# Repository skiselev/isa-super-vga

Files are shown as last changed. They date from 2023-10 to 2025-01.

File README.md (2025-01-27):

# isa-super-vga
Trident TVGA9000i based Super VGA board

## Introduction

The ISA Super VGA card is based on the Trident TVGA9000i Super VGA controller IC. It offers excellent compatibility with the original IBM VGA, as well as a good emulation of older CGA, EGA, Hercules and MDA adapters. The ISA Super VGA card was designed to be used with the [Xi 8088 Processor Board](https://github.com/skiselev/xi_8088), but it also works in IBM PC/XT and their clones. It will work in 16-bit ISA slots of AT-compatible computers, but its performance will be inferior to 16-bit VGA cards.

Note: PCB Version 1.0 requires a rework for compatibility with the original IBM PC and IBM XT computers, please see the Errata section below. This errata was fixed in the PCB Version 1.1

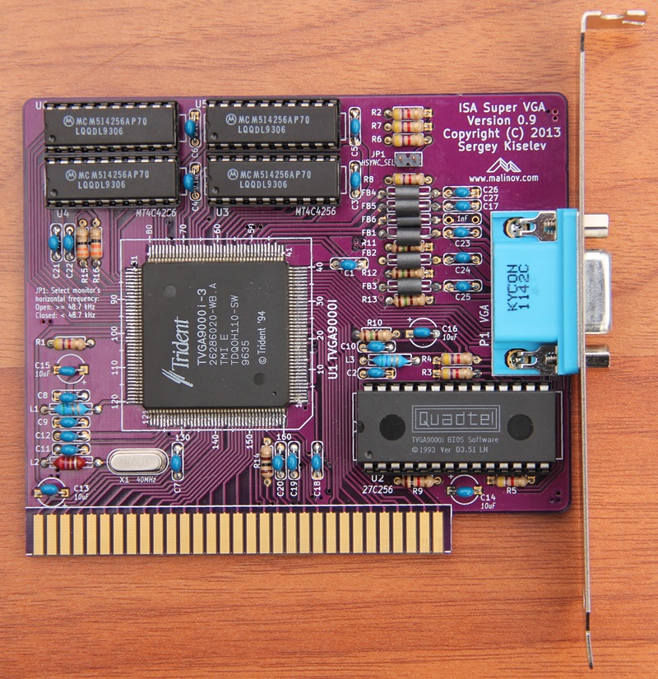
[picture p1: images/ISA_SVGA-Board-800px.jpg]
ISA SVGA V0.9 Assembled Board


## Specifications

* Supports 256 KiB or 512 KiB video memory using two or four 256 Kbit x 4 DRAM ICs.
* 8088-friendly VGA BIOS.
* Only 6 ICs (SVGA IC, BIOS, four DRAM chips), some capacitors, resistors and inductors.

## Hardware Documentation

### Schematic and PCB Layout

[Schematic - Version 1.1](KiCad/ISA_SVGA-Schematic-1.1.pdf)

[PCB Layout - Version 1.1](KiCad/ISA_SVGA-Board-1.1.pdf)

### Bill of Materials

Component Type     | Reference | Description                                               | Quantity | Possible sources and notes
------------------ | --------- | --------------------------------------------------------- | -------- | --------------------------
PCB                |           | ISA Super VGA PCB                                         | 1        | Refer to the [RetroBrew Computers Board Inventory page](https://retrobrewcomputers.org/doku.php?id=boardinventory) for ordering information, or order from a PCB manufacturer of your choice using provided Gerber or KiCad files. Here is [OSH Park project link](https://oshpark.com/shared_projects/M9jRwsu1).
Integrated Circuit | U1        | Trident TVGA9000i-3                                       | 1        | Utsource or other component dealers. Other TVGA9000i versions can be used (e.g. TVGA9000i-1)
Integrated Circuit | U2        | 27C256 UV erasable EPROM or OTP ROM                       | 1        | Unicorn Electronics, Jameco, Mouser (OTP ROM)
Integrated Circuit | U3 - U6   | Micron MT4C4256, Motorola MCM514256, or similar 256 Kbit x 4 DRAM, 70ns or less | 2 or 4 | Unicorn Electronics. Install 4 for the total memory of 512 KiB or two for 256 KiB.
Capacitor          | C1 - C12  | 0.1 uF ceramic, 5.08 mm pitch                             | 12       | Mouser 810-FG28X7R1H104KNT0 
Capacitor          | C13 - C16 | 10 uF, 16V, multilayer ceramic or tantalum, 5.08 mm pitch | 4        | Mouser 810-FG26X7R1E106KRT0 
Capacitor          | C17       | 1 nF ceramic, 5.08 mm pitch                               | 1        | Mouser 810-FG28C0G2A102JNT6
Capacitor          | C18       | 470 pF ceramic, 5.08 mm pitch                             | 1        | Mouser 810-FG28C0G1H471JNT0 
Capacitor          | C19       | 100 pF ceramic, 5.08 mm pitch                             | 1        | Mouser 810-FG28C0G1H101JNT0 
Capacitor          | C20 - C27 | 47 pF ceramic, 5.08 mm pitch                              | 8        | Mouser 810-FG28C0G1H470JNT0
Resistor           | R1 - R8   | 4.7 k, 1/4 W                                              | 8        | Mouser 291-4.7K-RC
Resistor           | R9        | 1 k, 1/4 W                                                | 1        | Mouser 291-1K-RC
Resistor           | R10 - R13 | 150 Ohm, 1/4 W                                            | 4        | Mouser 291-150-RC
Resistor           | R14       | 100 Ohm, 1/4 W                                            | 1        | Mouser 291-100-RC
Resistor           | R15, R16  | 33 Ohm, 1/4 W                                             | 2        | Mouser 291-33-RC
Connector          | P1        | DE15F, right angle PCB mount                              | 1        | Mouser 806-K66X-E15S-NJVESA, 571-1-1734344-1 (blue color), 806-K66X-E15S-NJ30
Connector          | JP1       | 2 pin header                                              | 1        | Mouser 649-68002-102HLF
Inductor           | L1, L3    | 5.7 uH                                                    | 2        | Mouser 542-78F5R6J-RC
Inductor           | L2        | 2.7 uH                                                    | 1        | Mouser 542-78F2R7-RC
Filter             | FB1 - FB6 | EMI Filter Bead                                           | 6        | Mouser 623-2743001112LF
Crystal            | X1        | 40 MHz                                                    | 1        | Mouser 815-ABL-40-B2
Crystal Insulator  | X1        | Bivar CI-192-028-SR                                       | 1        | Mouser 749-CI-192-028-SR, optional, to prevent crystal from shortcircuiting the traces underneath it.
IC Socket          | U2        | 28 pin 600 mil (wide) DIP socket                          | 1        | Mouser 517-4828-6000-CP
IC Socket          | U3 - U6   | 20 pin 300 mil (narrow) DIP socket                        | 4        | Mouser 517-4820-3000-CP
Bracket            |           | ISA card bracket - Keystone 9200-1                        | 1        | Mouser 534-9200-1, or a [3D printed bracket](https://www.thingiverse.com/thing:6473572)

### Construction Notes

#### Display Type Detection

* TVGA9000i VGA controller uses VGA connector pin 12 as **MONITOR** signal to detect the of type of the display. Older, pre-[DDC](https://en.wikipedia.org/wiki/Display_Data_Channel) displays made approximately until 1995, have that signal either unconnected - for color monitors, or grounded - for monochrome monitors. Newer displays use that signal as the DDC/SDA signal. Unfortunately, it can result in TVGA9000i incorrectly detecting the monitor as monochrome. If you're not planning to use monochrome monitor, you can skip FB6 and C17 components. In this case R6 will be pulling the MONITOR signal up, and TVGA9000i will detect the display as a color one.

## Changes

### Version 1.1

* Fix ALE errata. ALE signal is now connected to 5V
* Slightly move VGA DE-9F connector (about 1.27 mm up and 0.8 mm back) to better comply with ISA card size and bracket placement specifications

### Version 1.0

* Minor board modifications around JP1

## Errata

### Version 1.1
* C17 is incorrectly marked as 1 uF on the silkscreen. The correct value is 1 nF, as shown in the BoM. Also see **Display Type Detection** note above.

### Version 1.0

* The original IBM PC, the original IBM XT, and XT clones that closely follow IBM XT schematic do not implement the ALE signal properly. In these computers the ALE signal occasionally activated during DMA cycles, for example during memory refresh, while the address on the address bus is invalid. This confuses the Trident TVGA controller. The following rework is required to make ISA Super VGA work in these computers: The TVGA9000 ALE signal needs to be disconnected from the ISA ALE signal, and connected to the 5V power signal. The photo below shows such modification (photo credit: [keropi](https://forum.vcfed.org/index.php?members/keropi.23086/) at [VCFed forum](https://forum.vcfed.org/index.php)).

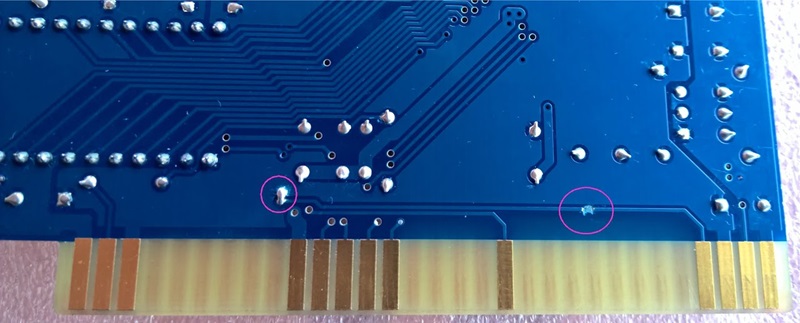
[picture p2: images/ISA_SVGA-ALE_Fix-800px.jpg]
ISA SVGA ALE Fix


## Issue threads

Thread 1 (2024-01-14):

thanks to the author & a couple of tips about building

giobbino, 2024-01-14:
First of all, thank you very much for your projects! I've built the ISA Super VGA card and now I'm waiting the PCBs and the parts for the 8088 and the FDD controller (I've already built the XT-IDE too). For us who can't design such complicated project on our own, these shared projects are very welcome!
----------------------------------------------------------------------
A couple of tips for anybody who will build the Super VGA card, based on my personal experience (I've built five units, all of them working fine):

1) if you planned to use just two RAM chips, use U3 and U4 sockets. Maybe you can use U5 and U6 instead, but I didn't try.

2) if your card doesn't work at first, and everything seems OK (solder joints, etc.), clean it with hot water, dish soap and a brush tooth (and of course dry it before to test!). I've found the Trident chip seems to be quite sensible to flux.

3) On Aliexpress you will easily find 5.6 uH inductance, that works fine instead of the 5.7 uH (I didn't find that value).

4) If you're uncertain about where to buy the VGA chip, I bought 3 units from this seller: https://www.aliexpress.com/item/1005005840301738.html  (seller: https://qimingyuan.aliexpress.com/store/1102671983).
They sent me the chips, that were clearly NOS, in a very good and resistant plastic package.

5) if you're uncertain about where to buy the RAM chips, I bought them from this seller:
https://www.aliexpress.com/item/1005005868001142.html (seller: https://www.aliexpress.com/store/3683098)
The chips worked fine.

Please note that I'm not affiliated to the sellers; it's just a suggestion based on my personal experience.

6) if you want to 3D print the bracket, get this one: https://www.tinkercad.com/things/l7DXN7Z4p88-vga-xt-8-bit-malinov-bracket

Hope it helps!

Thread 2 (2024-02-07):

3D printed bracket

giobbino, 2024-02-07:
For anybody who wish to print its own bracket, I released an STL file on Thingiverse:

https://www.thingiverse.com/thing:6473572

The same object also fits the Floppy disk and serial controller by Sergey.

hope it could help.

skiselev, 2024-02-07:
That looks great.
I've added it to the BoM.
Also added it to the [Monster FDC](https://github.com/skiselev/monster-fdc) project that uses the same bracket.
Thank you!

Closed 2024-02-07.

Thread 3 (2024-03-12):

BOM C20 -C27 capacitors, Mouser 810-FK28C0G1H470J, are obsolete and no longer available from Mouser.

wrljet, 2024-03-12:
Sergey,

The C20 - C27 47pF ceramic capacitors listed in the BOM, Mouser 810-FK28C0G1H470J, are obsolete and no longer available at Mouser.

Possible substitute:  810-FG28C0G1H470JNT0

The C18 and C19 small ceramic caps are also listed as not recommended for new designs.

Bill

skiselev, 2025-01-10:
Thanks for reporting!
Fixed here: https://github.com/skiselev/isa-super-vga/commit/ecea28522af35081063dd6427351b2361739830f
I also replaced other TDK FK series capacitors with the FG series.
Sorry, took some time to update the BoM...

Closed 2025-01-10.

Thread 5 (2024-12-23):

TVGA9000i ISA vs MCA pinout

kladogen, 2024-12-23:
Hi, I have built your design - thanks allot for it!! I have purchased 3 TVGA9000i chips but the board is not working, I have checked everything multiple times. So I just found that the TVGA9000i comes in two pinouts ISA and MCA, how can I check that the chips I have are ISA?

skiselev, 2024-12-23:
Any TVGA9000i chip can work either in ISA or MCA mode. The mode selected by this ISA SVGA board is ISA mode.
Sorry to hear your board is not working.
Do you get any signs of life at all? E.g. BIOS beeps? (If I recall correctly, there is a series of three or so short beeps if VGA memory test fails)
One common issue is soldering of the TVGA9000i chip, I'd recommend making sure that there are no solder bridges between pins. Also sometimes, pins are not thoroughly soldered. Both issues can be checked using a multimeter with thin, needle probes.

Hope this helps...

skiselev, 2025-01-10:
No response in a few weeks, closing the issue. Feel free to reopen or create another issue.

Closed 2025-01-10.

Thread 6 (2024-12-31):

EPROM speed

kladogen, 2024-12-31:
Hi, happy new year.
I would like to know what are the recommended ns for the EPROM. I have checked everything on my board - no shorts. Also I have checked the pcb connections according to schematic. I have changed RAMs no success. The only thing I have tried is faster EPROM since the ones I have are 100ns and 120ns. Could this be the problem? I'm using the tvga9000i-D4.01E.bin firmware.

kladogen, 2025-01-01:
The problem is not with the speed of the EPROM. The 100ns works fine.

Closed 2025-01-10.

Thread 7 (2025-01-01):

Crystal casing comes into contact with pads

kladogen, 2025-01-01:
The reason my board did not work was that the crystal case is conductive and came into contact with the pads under the crystal when the crystal is pushed to come in contact with the PCB (us it is supposed to). This causes a shortcircuit between the crystal pins and off course the circuit does not work. The solution is to leave to some space between the crystal and the board or to put some insulating tape under the crystal. In next version of the PCB the crystal pads could become smaller.

wrljet, 2025-01-01:
I don't have that issue with mine.  But, Digi-key, etc. sell little mylar insulators designed to go underneath standard crystal footprints.  I used to use these on my cheap PCBs years ago before I had solder mask.

kladogen, 2025-01-01:
Maybe a comment could be added to the BOM to save others from the same problem. It took me a week to find it after checking all connections on the PCB. The crystal was the last component I checked. At least it worked for 2025!

skiselev, 2025-01-10:
@wrljet do you have a part number, perhaps I can add that do the BoM?

wrljet, 2025-01-11:
Bivar (the manufacturer)  CI-192-028-SR

DigiKey  492-1039-ND
Mouser 749-CI-192-028-SR

But for what it's worth, I don't see a problem with the PCB causing a need for these insulators.
The expected crystal package won't short anything.

Bill

skiselev, 2025-01-27:
Thanks @wrljet!
I added the insulator to the BoM: https://github.com/skiselev/isa-super-vga/commit/ec1888477d16e3e7cb4c25714abd4655e719a455

Closed 2025-01-27.

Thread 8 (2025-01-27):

3D Printer Bracket problem

kladogen, 2025-01-27:
I have 3D printed the bracket (https://www.thingiverse.com/thing:6473572) but it is about 7mm longer at the top. Although the total length of the bracket is correct it seems it was designed before the VGA connector was moved, and it does not fit with current connector position.

skiselev, 2025-01-27:
I never ever moved the connector on that board.
It might be the issue with the 3D bracket design, in which case @giobbino is probably the right person to contact.
See: https://github.com/skiselev/isa-super-vga/issues/2

Closed 2025-01-27.

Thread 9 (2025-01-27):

Bracket dimensions seem to be incorrect

skiselev, 2025-01-27:
@giobbino Can you please check the bracket dimensions?
They should be the same as or very close to [Keystone Electronics
9200-1](https://www.mouser.com/datasheet/2/215/200-1-741899.pdf).
Looks like the position of the connector is not correct.
The center of the connector should be 49.83 mm from the top (50 mm is close enough). In your design it seems to be 55 mm or so.

giobbino, 2025-01-29:
I'm not sure why it's wrong for you, since it worked for me. However not a big deal, I can change the project and add a new file to the page.

Just to be sure: should I move the VGA connector hole 5 mm upward?

kladogen, 2025-01-29:
If the VGA connector is move 5mm up then the bracket corner should be at the correct height for a standard PC.

giobbino, 2025-01-29:
https://www.thingiverse.com/thing:6473572/files
added the new STL connector
cheers

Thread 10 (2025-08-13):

TIP: No need to order **Crystal Insulator** - Alternative

iosoft, 2025-08-13:
No need to buy/order **Crystal Insulator** (Bivar CI-192-028-SR / Mouser 749-CI-192-028-SR)

Just buy any cheapest 2-pin SMD type Crystal with plastic spacer.
Straighten the legs of the SMD type Crystal.
Remove and reuse the plastic spacer.
Fits perfectly.

See, I did -

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

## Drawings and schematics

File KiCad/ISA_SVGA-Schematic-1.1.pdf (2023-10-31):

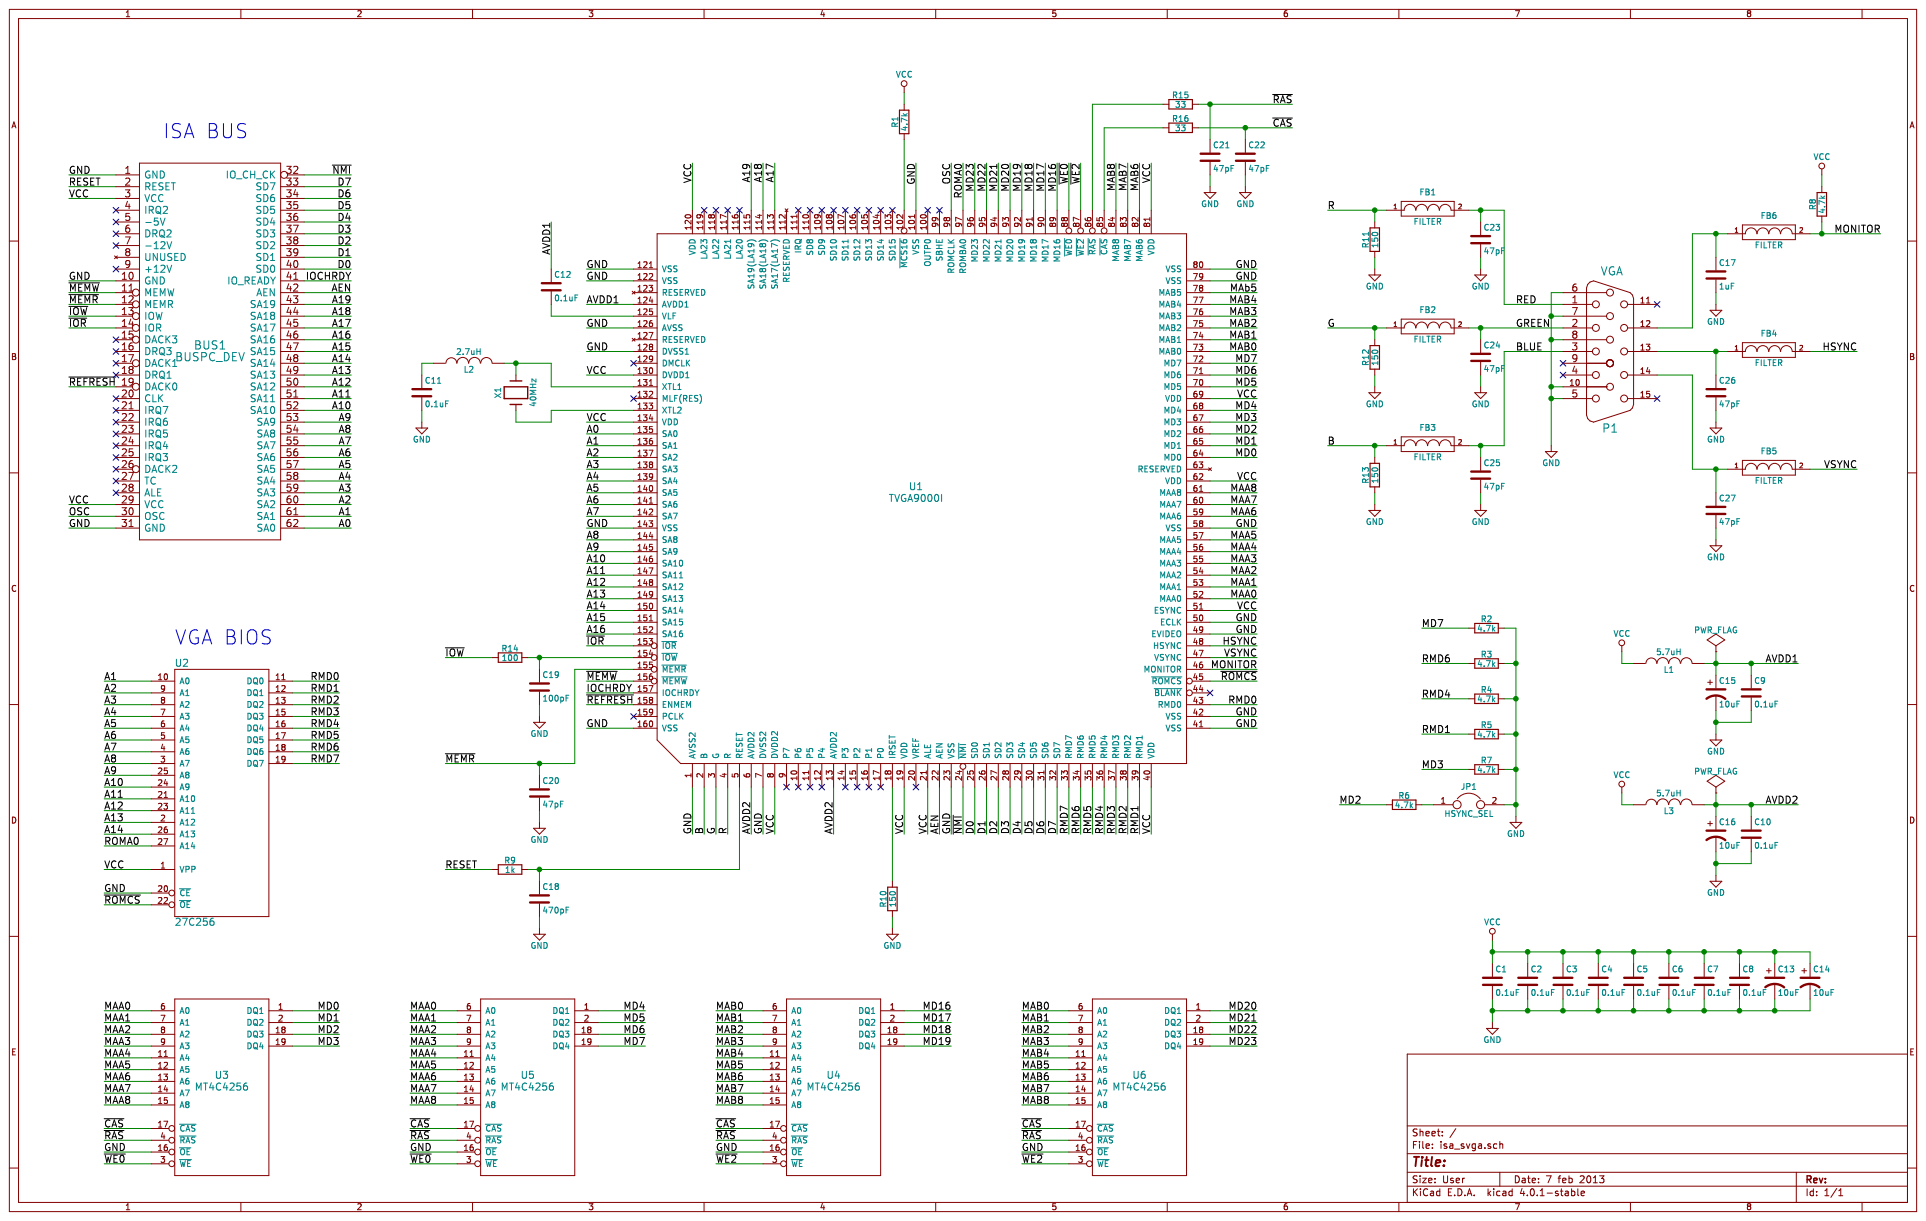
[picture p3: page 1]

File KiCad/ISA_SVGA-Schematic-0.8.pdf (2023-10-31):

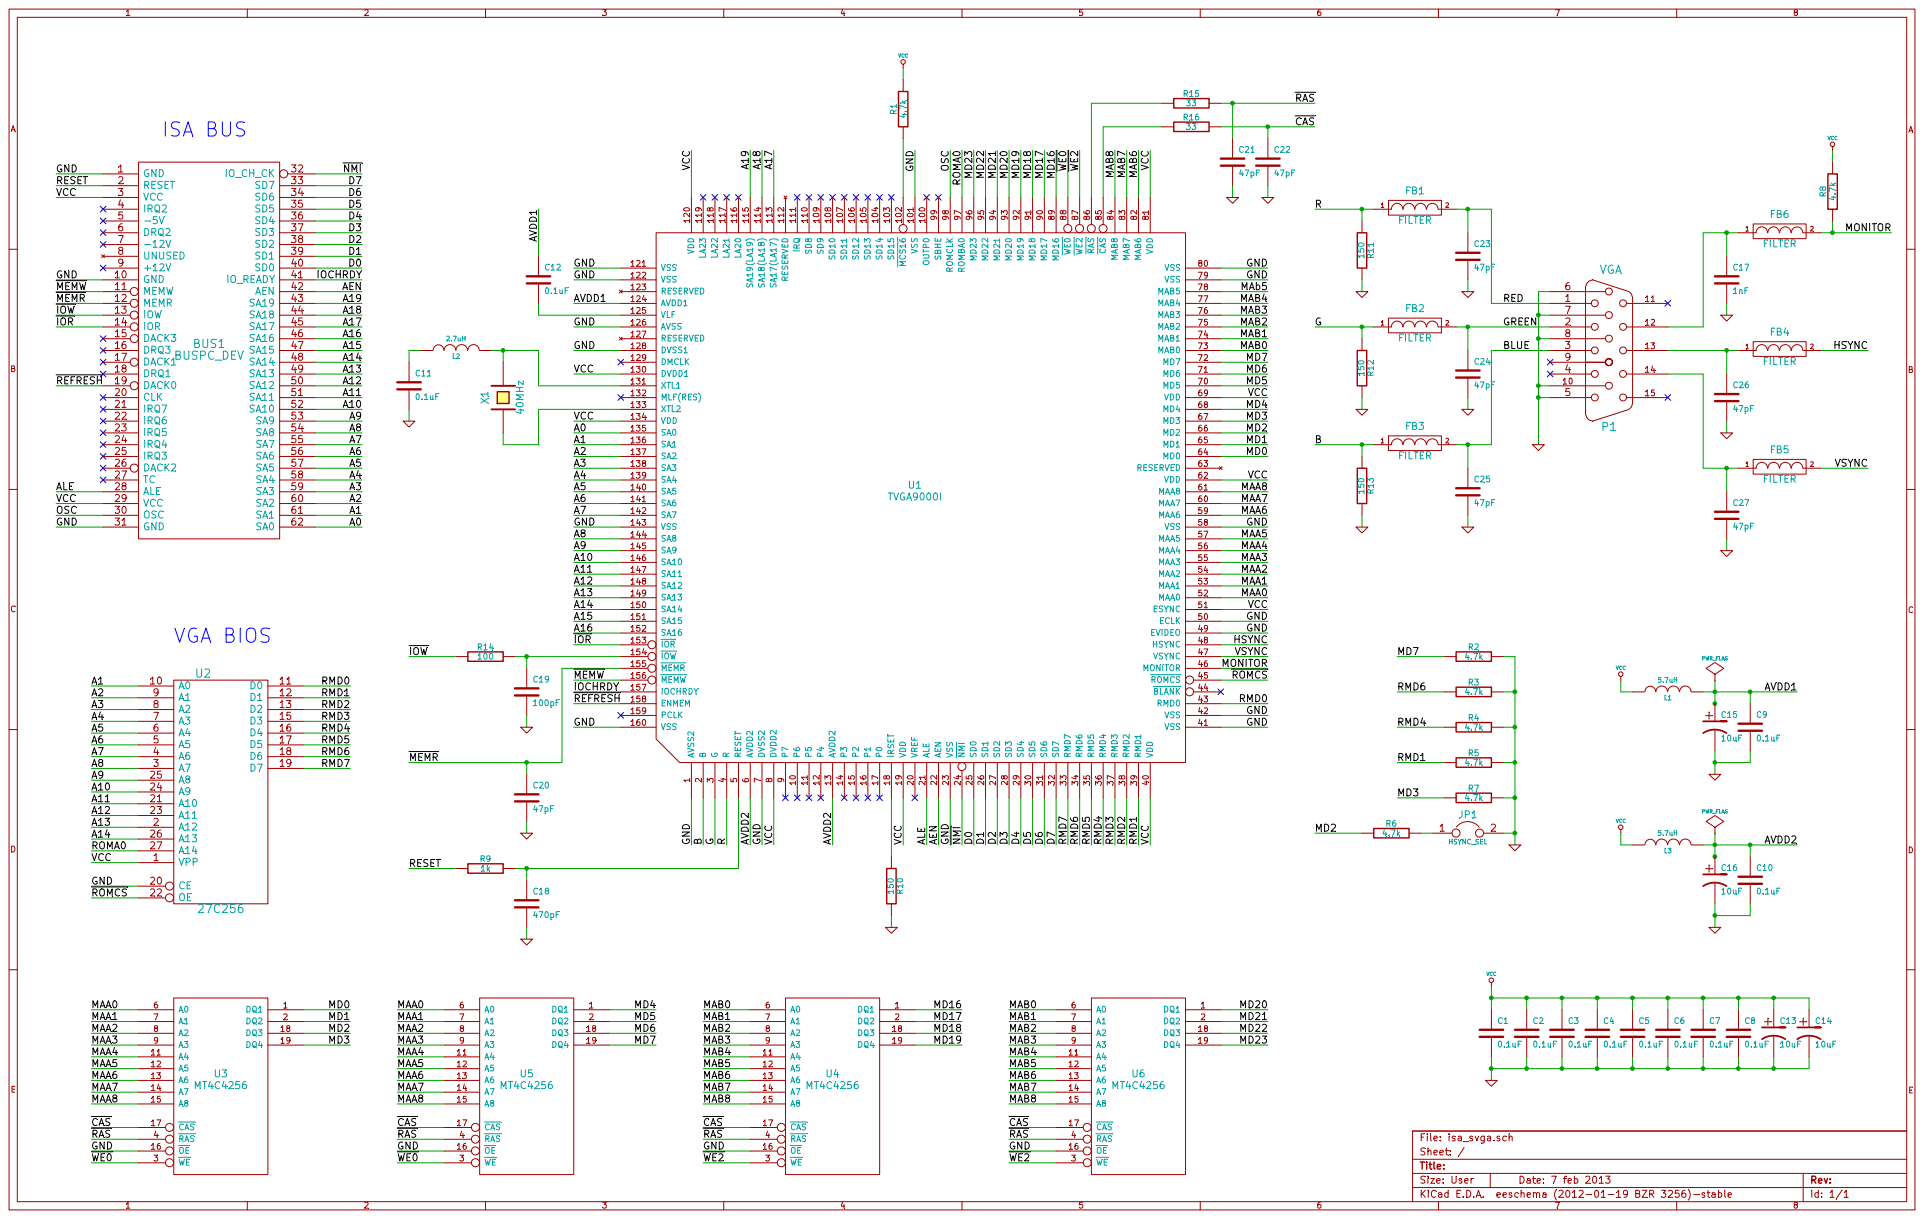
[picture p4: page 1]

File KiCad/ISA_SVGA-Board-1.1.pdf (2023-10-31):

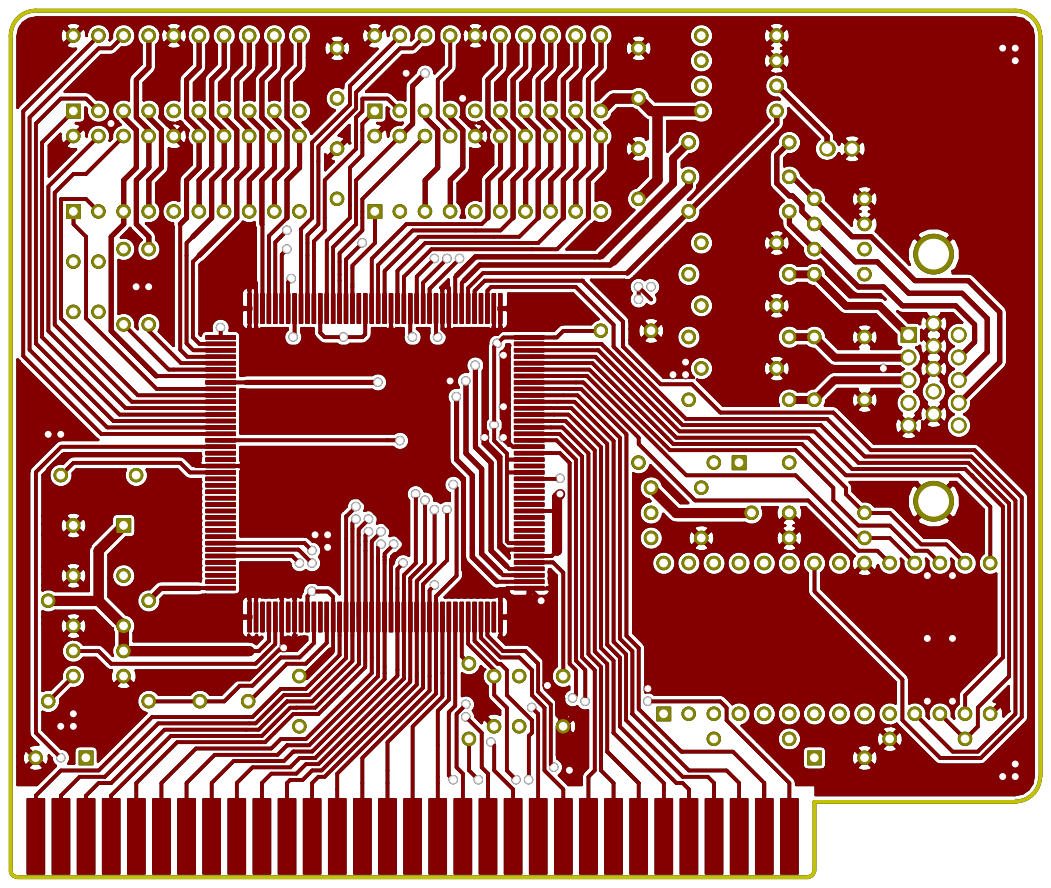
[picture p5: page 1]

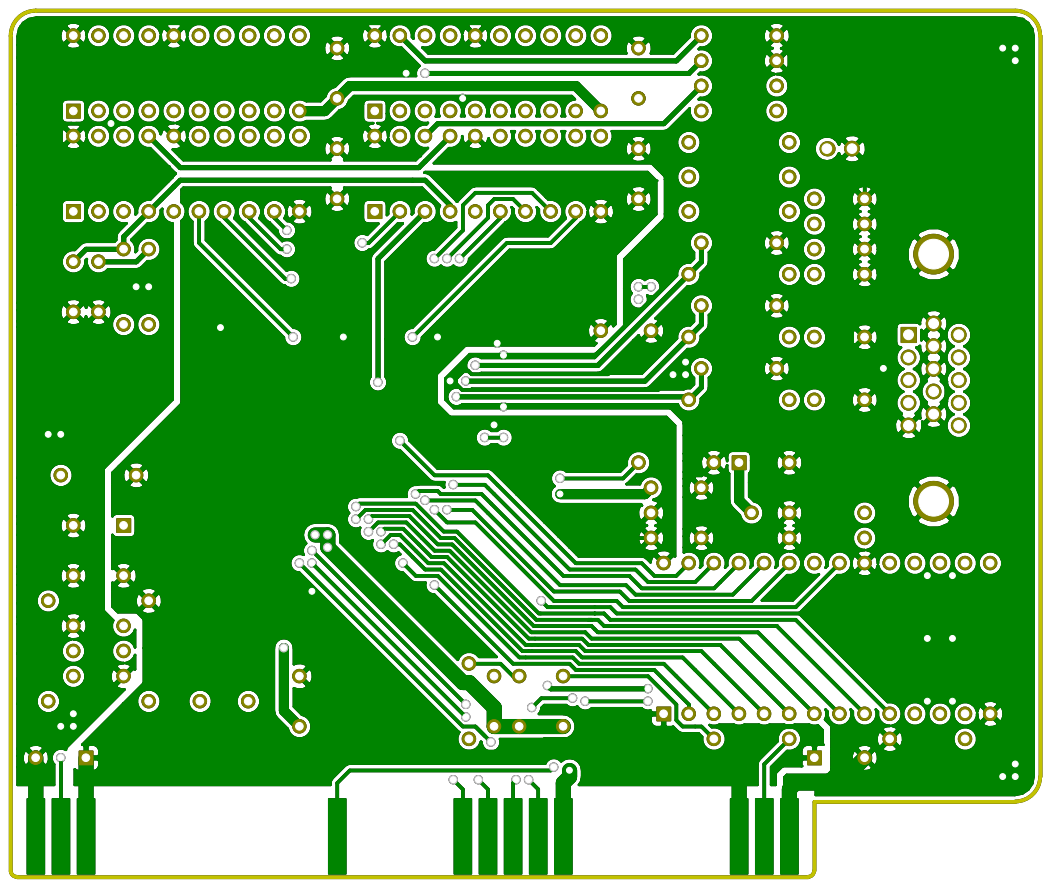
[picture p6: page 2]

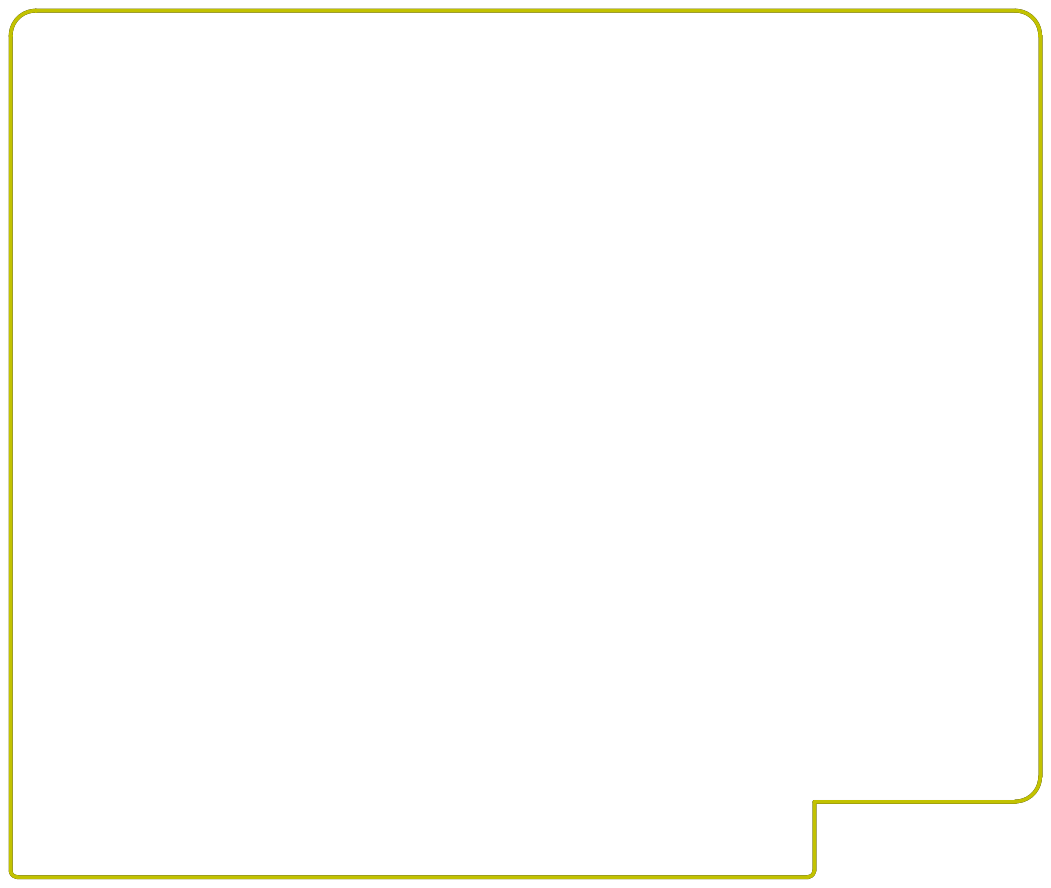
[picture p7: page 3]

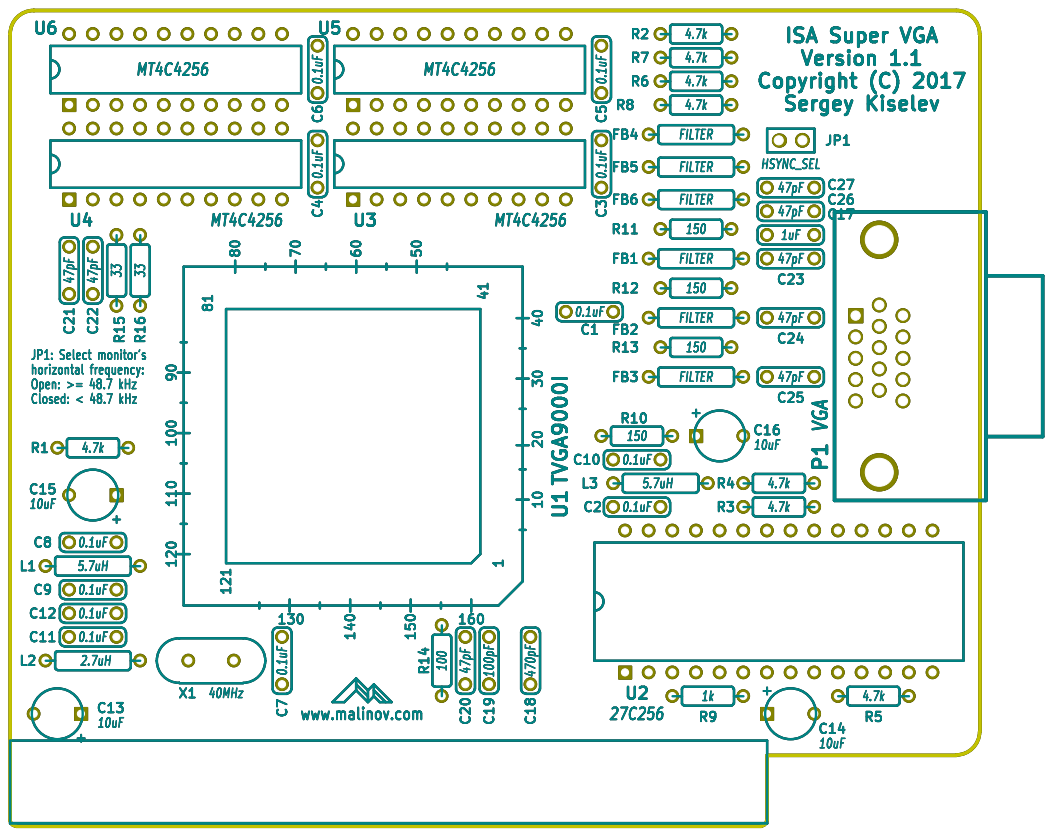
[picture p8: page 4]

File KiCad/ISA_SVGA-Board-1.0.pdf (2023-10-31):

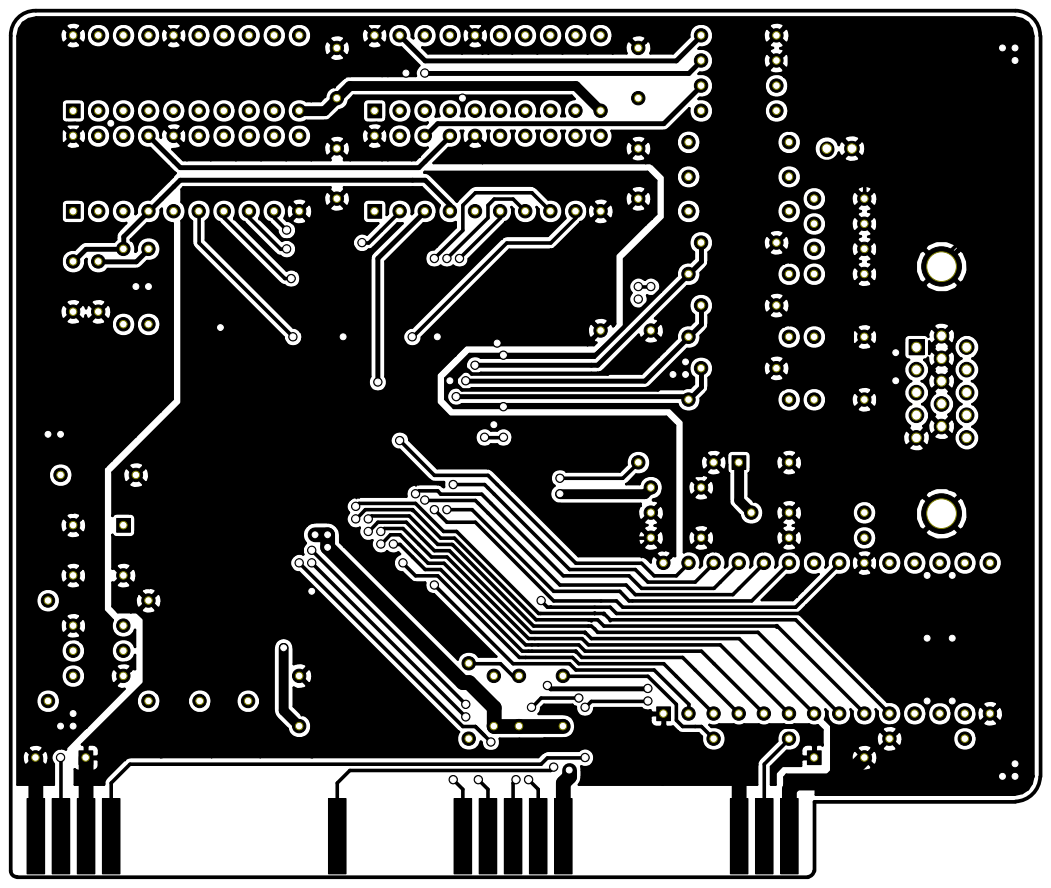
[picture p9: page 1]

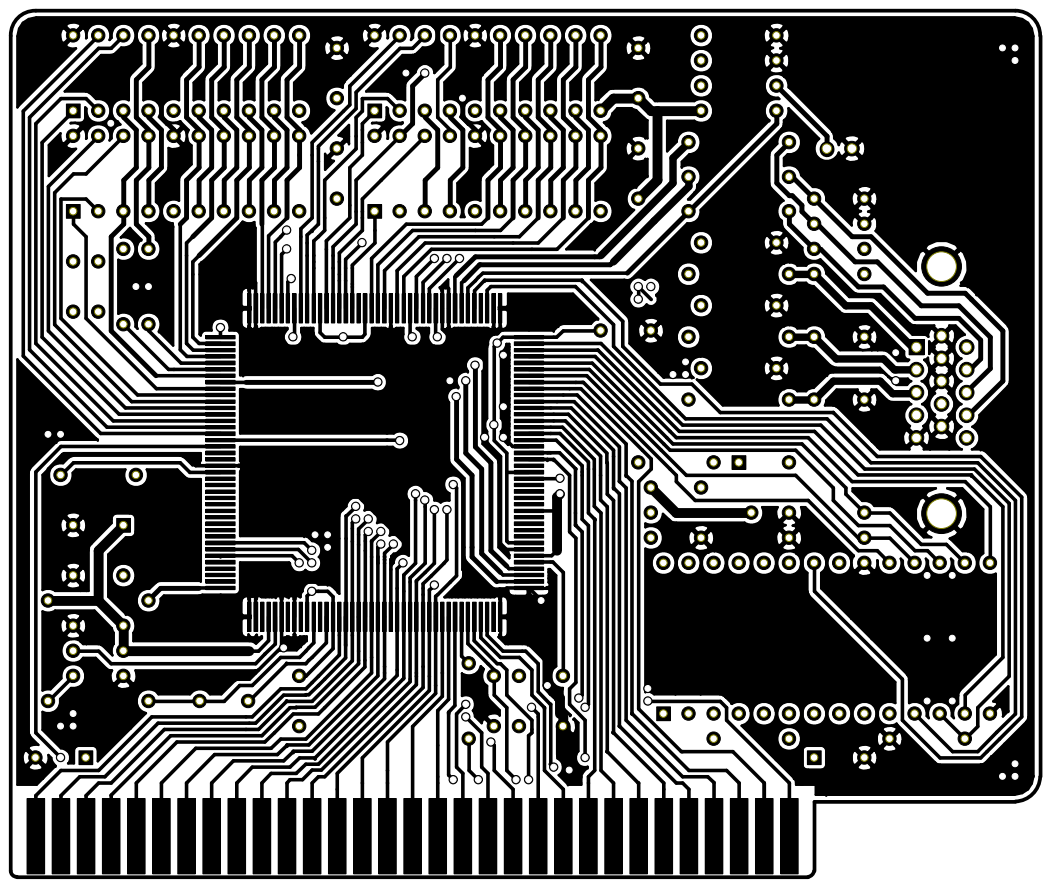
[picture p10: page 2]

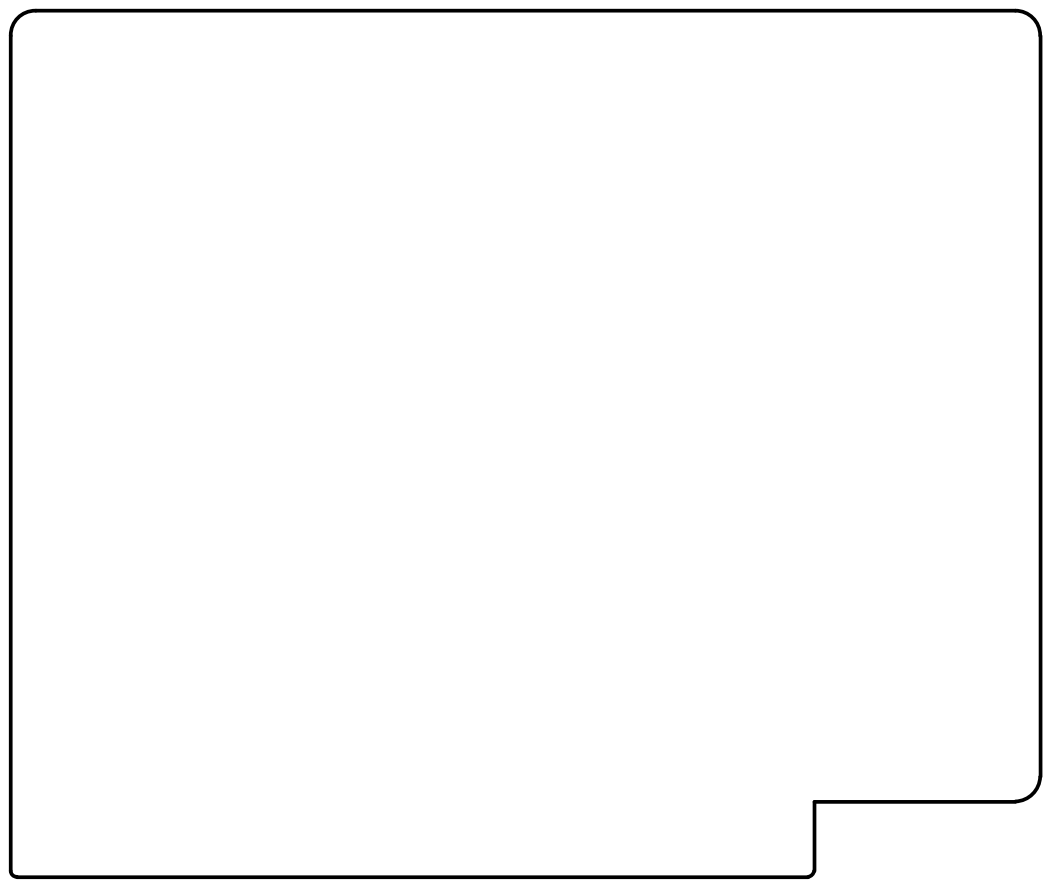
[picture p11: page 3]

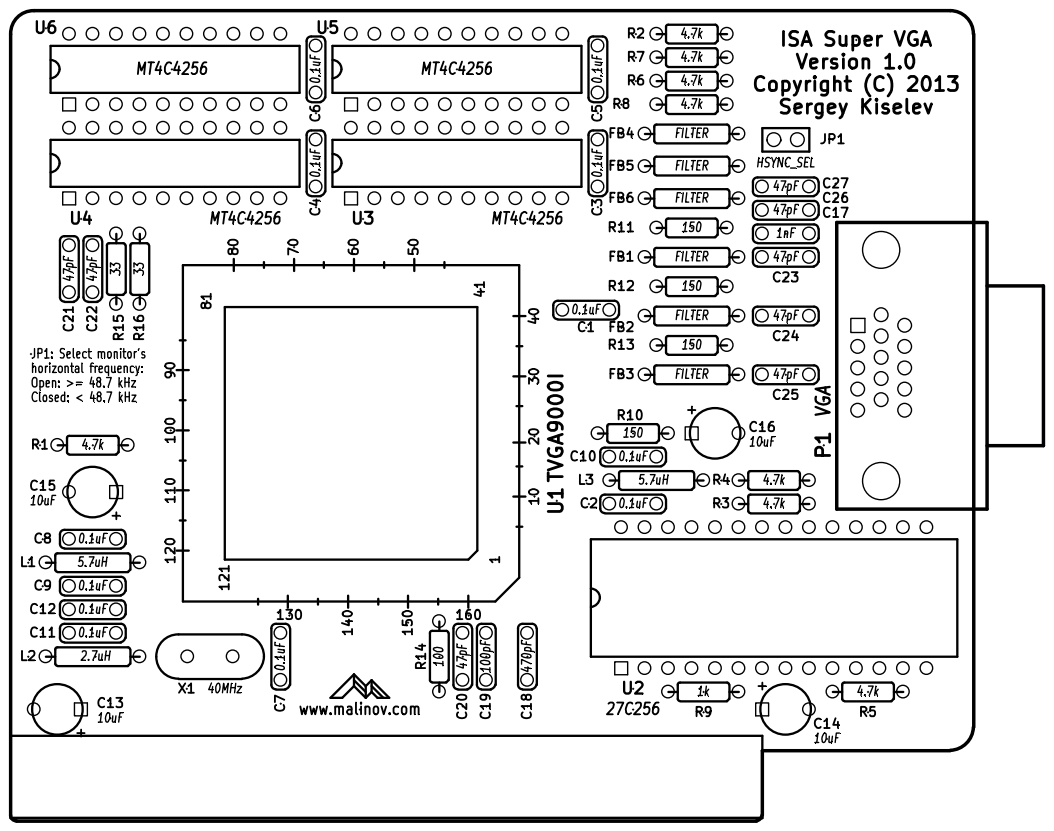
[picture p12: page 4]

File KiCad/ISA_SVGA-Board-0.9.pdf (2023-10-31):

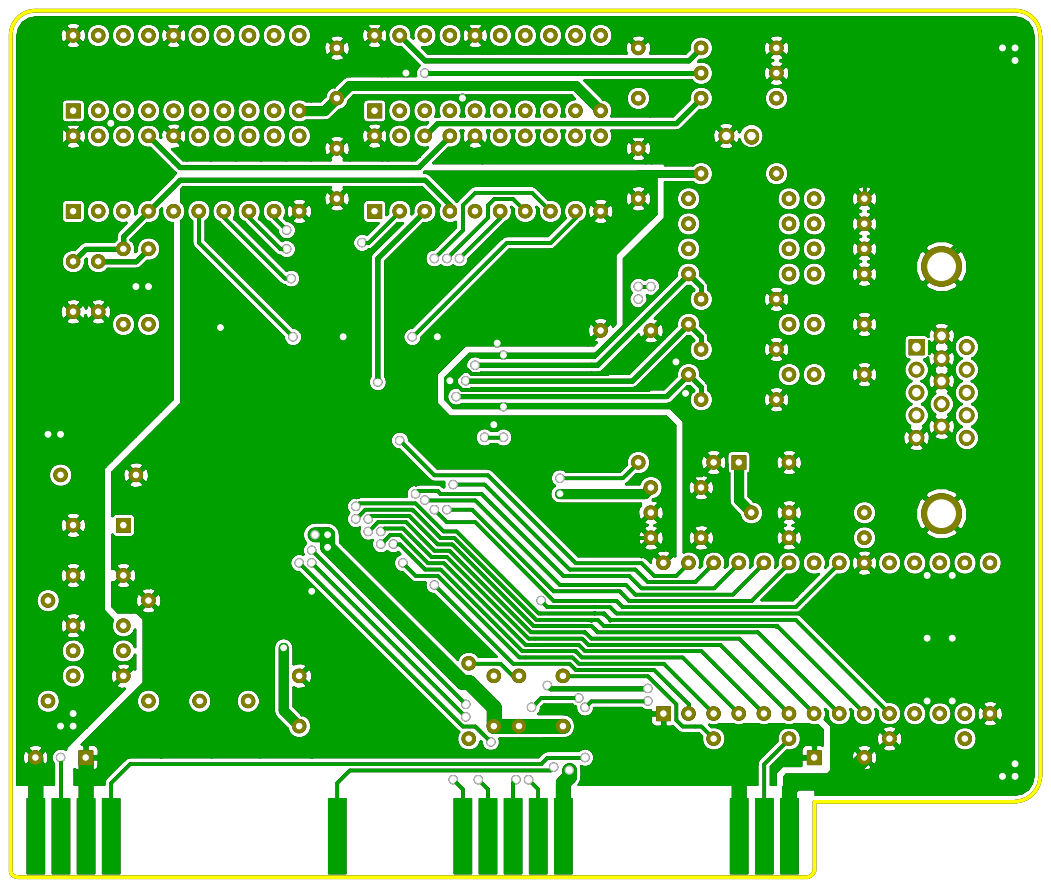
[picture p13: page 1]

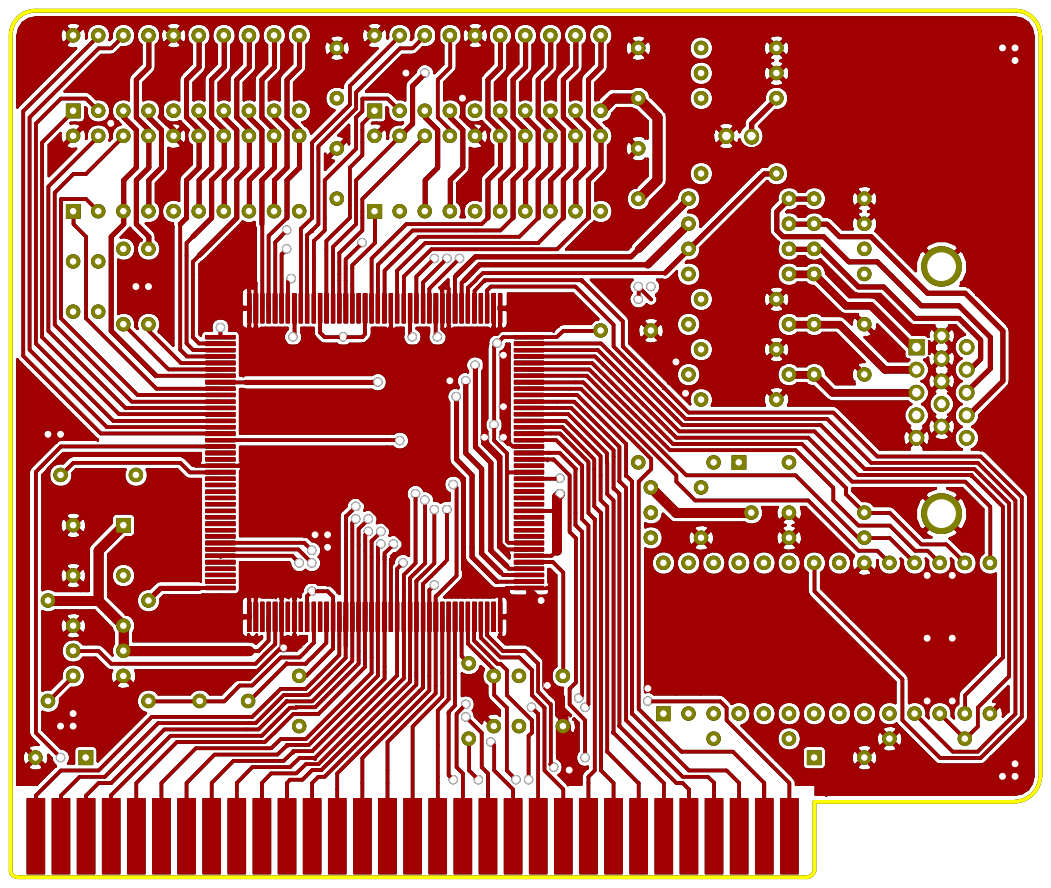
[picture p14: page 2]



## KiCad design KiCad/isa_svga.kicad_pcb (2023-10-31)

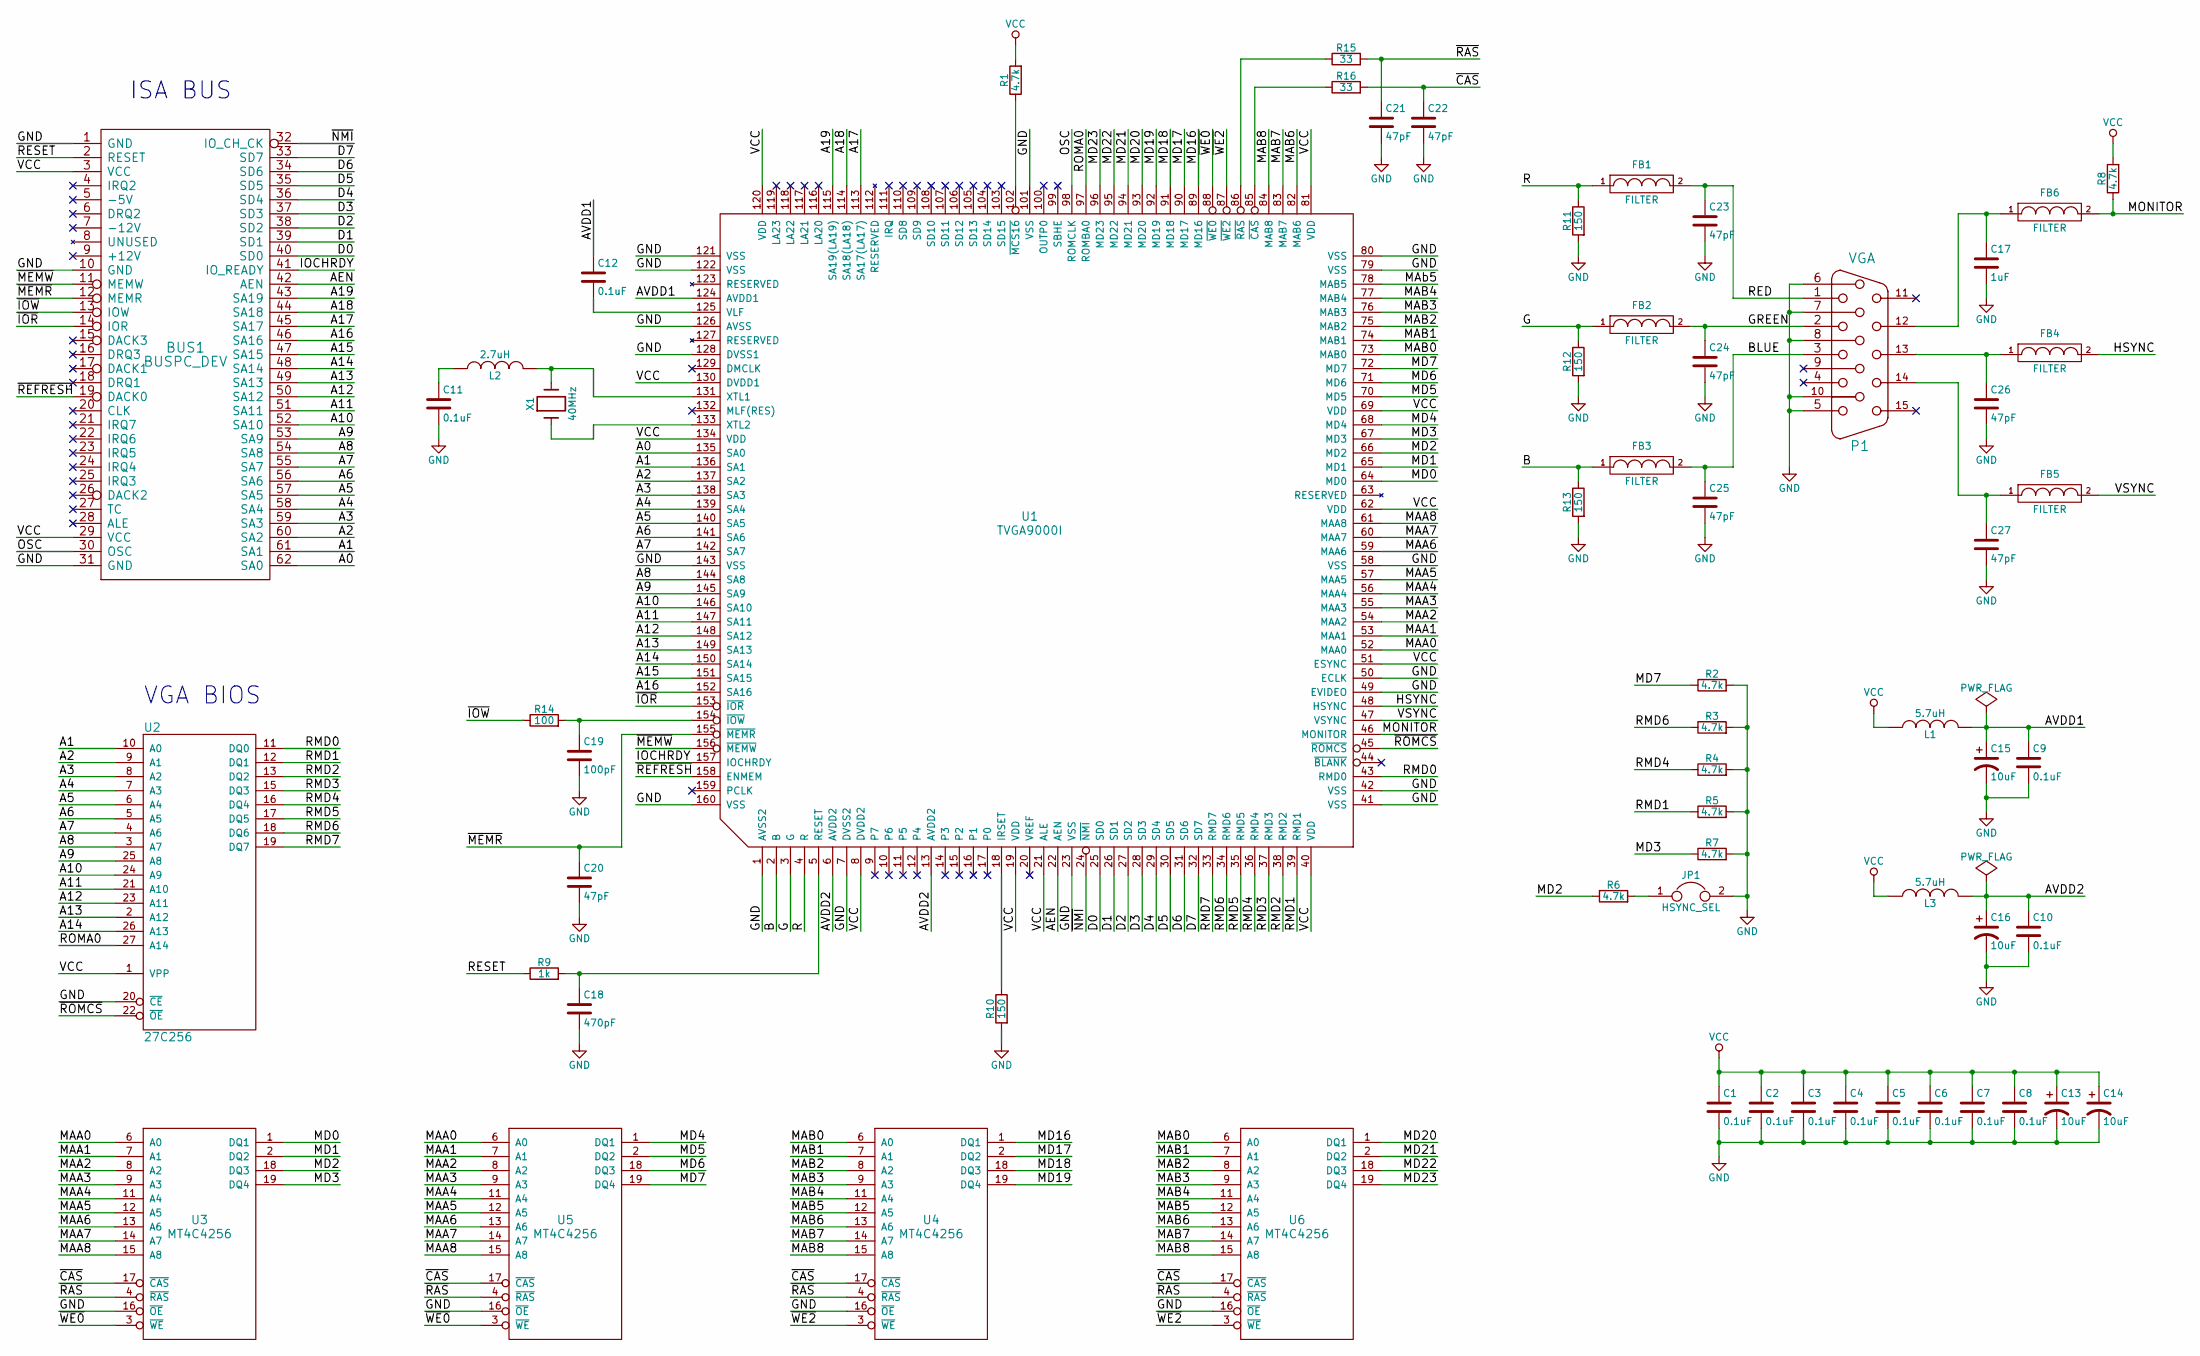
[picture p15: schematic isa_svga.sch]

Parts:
BUS1: BUSPC_DEV; Conn_Edge_ISA8
C1, C2, C3, C4, C5, C6, C7, C8, C9, C10, C11, C12: 0.1uF; Cap_Cer_508
C13, C14, C15, C16: 10uF; Cap_Tant_508
C17: 1uF; Cap_Cer_508
C18: 470pF; Cap_Cer_508
C19: 100pF; Cap_Cer_508
C20, C21, C22, C23, C24, C25, C26, C27: 47pF; Cap_Cer_508
FB1, FB2, FB3, FB4, FB5, FB6: FILTER; Res_1016
JP1: HSYNC_SEL; Conn_Pin_Header_2x1_2.54mm_NoKey
L1, L3: 5.7uH; Res_1016
L2: 2.7uH; Res_1016
P1: VGA; Conn_Dsub_DE15F
R1, R2, R3, R4, R5, R6, R7, R8: 4.7k; Res_762
R9: 1k; Res_762
R10, R11, R12, R13: 150; Res_762
R14: 100; Res_762
R15, R16: 33; Res_762
U1: TVGA9000I; IC_PQFP-160
U2: 27C256; IC_DIP28_600
U3, U4, U5, U6: MT4C4256; IC_DIP20_300
X1: 40MHz; Crystal_HC-49U_Vert

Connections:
/A0: BUS1.62 (SA0), U1.135 (SA0)
/A1: BUS1.61 (SA1), U1.136 (SA1), U2.10 (A0)
/A2: BUS1.60 (SA2), U1.137 (SA2), U2.9 (A1)
/A3: BUS1.59 (SA3), U1.138 (SA3), U2.8 (A2)
/A4: BUS1.58 (SA4), U1.139 (SA4), U2.7 (A3)
/A5: BUS1.57 (SA5), U1.140 (SA5), U2.6 (A4)
/A6: BUS1.56 (SA6), U1.141 (SA6), U2.5 (A5)
/A7: BUS1.55 (SA7), U1.142 (SA7), U2.4 (A6)
/A8: BUS1.54 (SA8), U1.144 (SA8), U2.3 (A7)
/A9: BUS1.53 (SA9), U1.145 (SA9), U2.25 (A8)
/A10: BUS1.52 (SA10), U1.146 (SA10), U2.24 (A9)
/A11: BUS1.51 (SA11), U1.147 (SA11), U2.21 (A10)
/A12: BUS1.50 (SA12), U1.148 (SA12), U2.23 (A11)
/A13: BUS1.49 (SA13), U1.149 (SA13), U2.2 (A12)
/A14: BUS1.48 (SA14), U1.150 (SA14), U2.26 (A13)
/A15: BUS1.47 (SA15), U1.151 (SA15)
/A16: BUS1.46 (SA16), U1.152 (SA16)
/A17: BUS1.45 (SA17), U1.113 (SA17(LA17))
/A18: BUS1.44 (SA18), U1.114 (SA18(LA18))
/A19: BUS1.43 (SA19), U1.115 (SA19(LA19))
/AEN: BUS1.42 (AEN), U1.22 (AEN)
/AVDD1: C9.1, C12.1, C15.1, L1.2, U1.124 (AVDD1)
/AVDD2: C10.1, C16.1, L3.2, U1.6 (AVDD2), U1.13 (AVDD2)
/B: FB3.1, R13.1, U1.2 (B)
/BLUE: C25.1, FB3.2, P1.3
/D0: BUS1.40 (SD0), U1.25 (SD0)
/D1: BUS1.39 (SD1), U1.26 (SD1)
/D2: BUS1.38 (SD2), U1.27 (SD2)
/D3: BUS1.37 (SD3), U1.28 (SD3)
/D4: BUS1.36 (SD4), U1.29 (SD4)
/D5: BUS1.35 (SD5), U1.30 (SD5)
/D6: BUS1.34 (SD6), U1.31 (SD6)
/D7: BUS1.33 (SD7), U1.32 (SD7)
/G: FB2.1, R12.1, U1.3 (G)
/GREEN: C24.1, FB2.2, P1.2
/HSYNC: FB4.2, U1.48 (HSYNC)
/IOCHRDY: BUS1.41 (IO_READY), U1.157 (IOCHRDY)
/MAA0: U1.52 (MAA0), U3.6 (A0), U5.6 (A0)
/MAA1: U1.53 (MAA1), U3.7 (A1), U5.7 (A1)
/MAA2: U1.54 (MAA2), U3.8 (A2), U5.8 (A2)
/MAA3: U1.55 (MAA3), U3.9 (A3), U5.9 (A3)
/MAA4: U1.56 (MAA4), U3.11 (A4), U5.11 (A4)
/MAA5: U1.57 (MAA5), U3.12 (A5), U5.12 (A5)
/MAA6: U1.59 (MAA6), U3.13 (A6), U5.13 (A6)
/MAA7: U1.60 (MAA7), U3.14 (A7), U5.14 (A7)
/MAA8: U1.61 (MAA8), U3.15 (A8), U5.15 (A8)
/MAB0: U1.73 (MAB0), U4.6 (A0), U6.6 (A0)
/MAB1: U1.74 (MAB1), U4.7 (A1), U6.7 (A1)
/MAB2: U1.75 (MAB2), U4.8 (A2), U6.8 (A2)
/MAB3: U1.76 (MAB3), U4.9 (A3), U6.9 (A3)
/MAB4: U1.77 (MAB4), U4.11 (A4), U6.11 (A4)
/MAB5: U1.78 (MAB5), U4.12 (A5), U6.12 (A5)
/MAB6: U1.82 (MAB6), U4.13 (A6), U6.13 (A6)
/MAB7: U1.83 (MAB7), U4.14 (A7), U6.14 (A7)
/MAB8: U1.84 (MAB8), U4.15 (A8), U6.15 (A8)
/MD0: U1.64 (MD0), U3.1 (DQ1)
/MD1: U1.65 (MD1), U3.2 (DQ2)
/MD2: R6.1, U1.66 (MD2), U3.18 (DQ3)
/MD3: R7.1, U1.67 (MD3), U3.19 (DQ4)
/MD4: U1.68 (MD4), U5.1 (DQ1)
/MD5: U1.70 (MD5), U5.2 (DQ2)
/MD6: U1.71 (MD6), U5.18 (DQ3)
/MD7: R2.1, U1.72 (MD7), U5.19 (DQ4)
/MD16: U1.89 (MD16), U4.1 (DQ1)
/MD17: U1.90 (MD17), U4.2 (DQ2)
/MD18: U1.91 (MD18), U4.18 (DQ3)
/MD19: U1.92 (MD19), U4.19 (DQ4)
/MD20: U1.93 (MD20), U6.1 (DQ1)
/MD21: U1.94 (MD21), U6.2 (DQ2)
/MD22: U1.95 (MD22), U6.18 (DQ3)
/MD23: U1.96 (MD23), U6.19 (DQ4)
/MONITOR: FB6.2, R8.1, U1.46 (MONITOR)
/OSC: BUS1.30 (OSC), U1.98 (ROMCLK)
/R: FB1.1, R11.1, U1.4 (R)
/RED: C23.1, FB1.2, P1.1
/RESET: BUS1.2 (RESET), R9.1
/RMD0: U1.43 (RMD0), U2.11 (DQ0)
/RMD1: R5.1, U1.39 (RMD1), U2.12 (DQ1)
/RMD2: U1.38 (RMD2), U2.13 (DQ2)
/RMD3: U1.37 (RMD3), U2.15 (DQ3)
/RMD4: R4.1, U1.36 (RMD4), U2.16 (DQ4)
/RMD5: U1.35 (RMD5), U2.17 (DQ5)
/RMD6: R3.1, U1.34 (RMD6), U2.18 (DQ6)
/RMD7: U1.33 (RMD7), U2.19 (DQ7)
/ROMA0: U1.97 (ROMBA0), U2.27 (A14)
/VSYNC: FB5.2, U1.47 (VSYNC)
/~CAS: C22.1, R16.2, U3.17 (~CAS), U4.17 (~CAS), U5.17 (~CAS), U6.17 (~CAS)
/~IOR: BUS1.14 (IOR), U1.153 (~IOR)
/~IOW: BUS1.13 (IOW), R14.1
/~MEMR: BUS1.12 (MEMR), C20.1, U1.155 (~MEMR)
/~MEMW: BUS1.11 (MEMW), U1.156 (~MEMW)
/~NMI: BUS1.32 (IO_CH_CK), U1.24 (~NMI)
/~RAS: C21.1, R15.2, U3.4 (~RAS), U4.4 (~RAS), U5.4 (~RAS), U6.4 (~RAS)
/~REFRESH: BUS1.19 (DACK0), U1.158 (ENMEM)
/~ROMCS: U1.45 (~ROMCS), U2.22 (~OE)
/~WE0: U1.88 (~WE0), U3.3 (~WE), U5.3 (~WE)
/~WE2: U1.87 (~WE2), U4.3 (~WE), U6.3 (~WE)
GND: BUS1.1 (GND), BUS1.10 (GND), BUS1.31 (GND), C1.2, C2.2, C3.2, C4.2, C5.2, C6.2, C7.2, C8.2, C9.2, C10.2, C11.2, C13.2, C14.2, C15.2, C16.2, C17.2, C18.2, C19.2, C20.2, C21.2, C22.2, C23.2, C24.2, C25.2, C26.2, C27.2, JP1.2, P1.5, P1.6, P1.7, P1.8, P1.10, R2.2, R3.2, R4.2, R5.2, R7.2, R10.2, R11.2, R12.2, R13.2, U1.1 (AVSS2), U1.7 (DVSS2), U1.23 (VSS), U1.41 (VSS), U1.42 (VSS), U1.49 (EVIDEO), U1.50 (ECLK), U1.58 (VSS), U1.79 (VSS), U1.80 (VSS), U1.101 (VSS), U1.121 (VSS), U1.122 (VSS), U1.126 (AVSS), U1.128 (DVSS1), U1.143 (VSS), U1.160 (VSS), U2.14 (GND), U2.20 (~CE), U3.16 (~OE), U3.20 (GND), U4.16 (~OE), U4.20 (GND), U5.16 (~OE), U5.20 (GND), U6.16 (~OE), U6.20 (GND)
unnamed: C11.1, L2.1
unnamed: C12.2, U1.125 (VLF)
unnamed: C17.1, FB6.1, P1.12
unnamed: C18.1, R9.2, U1.5 (RESET)
unnamed: C19.1, R14.2, U1.154 (~IOW)
unnamed: C26.1, FB4.1, P1.13
unnamed: C27.1, FB5.1, P1.14
unnamed: JP1.1, R6.2
unnamed: L2.2, U1.131 (XTL1), X1.2
unnamed: R1.1, U1.102 (~MCS16)
unnamed: R10.1, U1.18 (IRSET)
unnamed: R15.1, U1.86 (~RAS)
unnamed: R16.1, U1.85 (~CAS)
unnamed: U1.133 (XTL2), X1.1
VCC: BUS1.3 (VCC), BUS1.29 (VCC), C1.1, C2.1, C3.1, C4.1, C5.1, C6.1, C7.1, C8.1, C13.1, C14.1, L1.1, L3.1, R1.2, R8.2, U1.8 (DVDD2), U1.19 (VDD), U1.21 (ALE), U1.40 (VDD), U1.51 (ESYNC), U1.62 (VDD), U1.69 (VDD), U1.81 (VDD), U1.120 (VDD), U1.130 (DVDD1), U1.134 (VDD), U2.1 (VPP), U2.28 (VCC), U3.10 (VCC), U4.10 (VCC), U5.10 (VCC), U6.10 (VCC)

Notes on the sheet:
VGA BIOS
ISA BUS

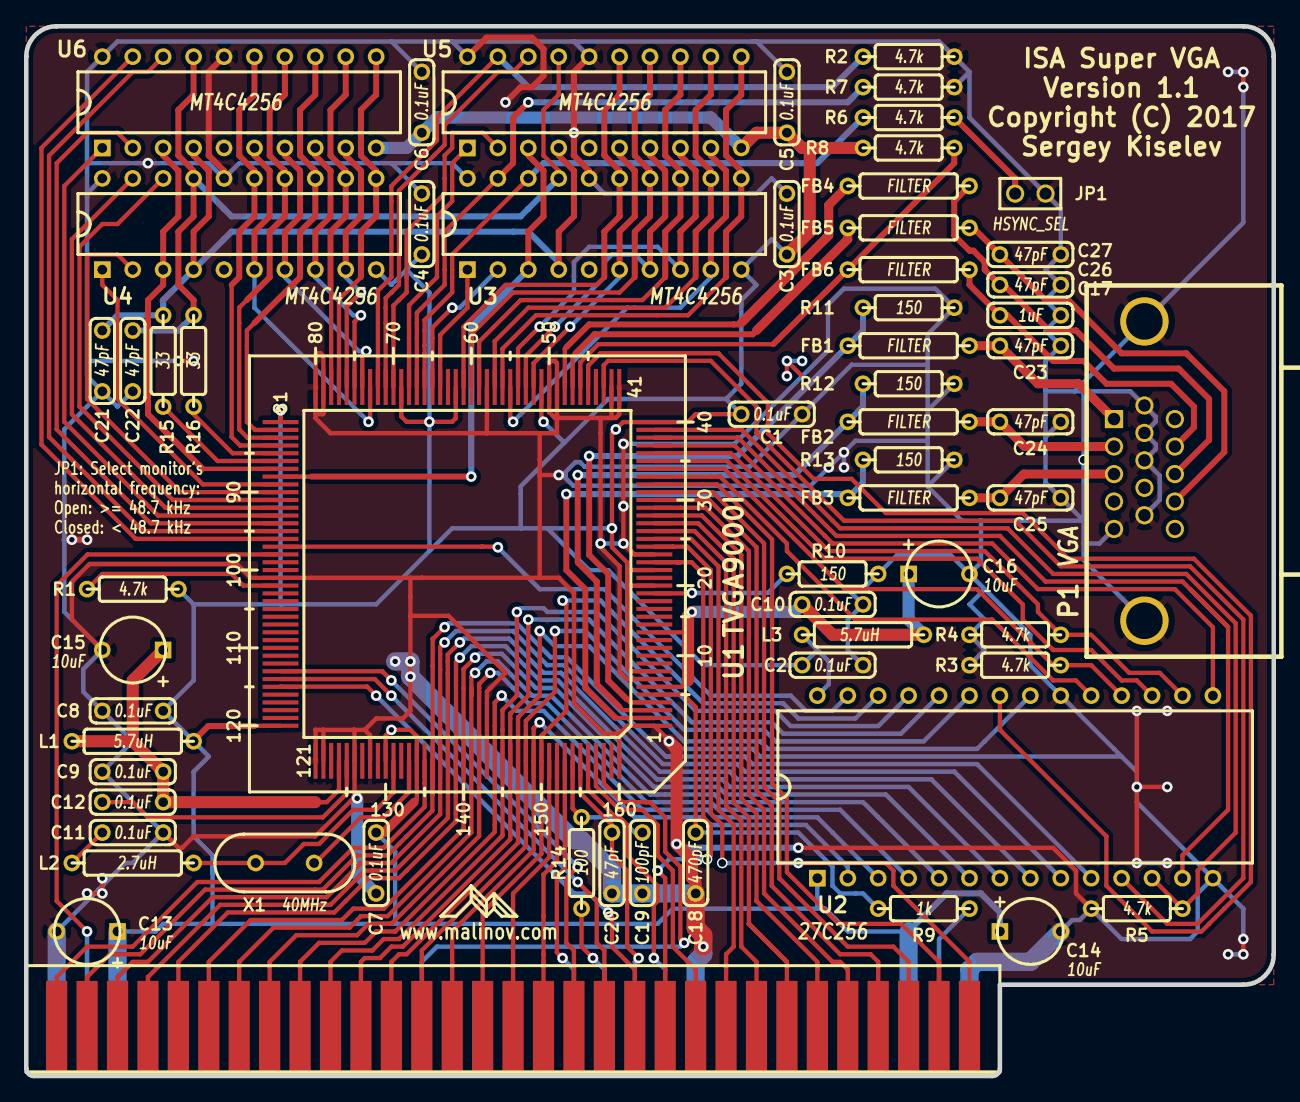
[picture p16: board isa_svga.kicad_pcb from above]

Board: 2 copper layers, 104.1 x 87.6 mm, 62 parts (0 on the bottom side), 113 nets.

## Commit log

2023-10-31 Add v0.9 files
    [isa_svga.brd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]
2023-10-31 Add v1.0 files
    [isa_svga.brd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]
2023-10-31 Add v1.0 board pdf
2023-10-31 Add v1.1 files
    [isa_svga-B_Mask.gbs, isa_svga-B_SilkS.gbo, isa_svga-Back.gbl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]
2023-10-31 Add schematic and PCB links, add notes about MONITOR signal
2024-02-07 Add link to a 3D printed bracket
2025-01-10 README: Replace TDK FK series capacitors with FG series
    Replace TDK FK series capacitors that are not recommended for new designs, with newer FG series capacitors
2025-01-27 README: BoM: Add an insulator for the crystal

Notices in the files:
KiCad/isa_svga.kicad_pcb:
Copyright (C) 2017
